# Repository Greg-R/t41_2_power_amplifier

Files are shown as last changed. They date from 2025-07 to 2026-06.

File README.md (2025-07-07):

# T41-2 Power Amplifier Version 1.7

This is the PCB for the Power Amplifier for the T41 "Software Defined Transceiver".
This PCB was designed using the open-source design tool Kicad 9.0.

The Power Amplifier is designed to driven by the T41-2 Low Power Amplifier, described here:

<https://github.com/Greg-R/t41_2_low_power_amplifier>

The Low Power Amplifier combined with the Power Amplifier are intended to replace the
original V11 Power Amplifier which uses IRF510 switching MOSFETs in the final amplifier
stage.  This new design will improve all aspects of power amplifier performance, 
including linearity, power, efficiency, and bandwidth.  An important difference is that
the amplifier operates from a 13.8 volt supply.  No "boost" module is required.

The schematic is here:

<https://github.com/Greg-R/t41_2_power_amplifier/blob/main/doc/t41_2_power_amplifier.pdf>

# Licensing

Please note the included license files.  The software license, GNU GENERAL PUBLIC LICENSE
Version 3, covers the design files.
The hardware license, CERN Open Hardware Licence Version 2 - Strongly Reciprocal, covers
the PCB and circuitry.

# Design Details

## Amplifier Design Notes 

The Power Amplifier is a conventional push-pull circuit using Mitsubishi RD16HHF1 devices.

The input network is an impedance matching transformer with a center-tapped secondary.
A resistive network is used for DC gate bias of the MOSFETS as well as for stability.
The two MOSFETs have independent bias adjustments due to the wide threshold voltage
variation of MOSFET devices.

A bifilar wound inductor provides DC bias to the MOSFET drains.

Each MOSFET has a transformer wound on a binocular core.  These are combined in parallel
on the output.  This results in a compact layout while preserving good bandwidth.

## DC Biasing and Thermal Protection Circuits 

A 10 volt regulator provides the bias voltage to the potentiometers which are used to set
the MOSFET quiescent bias currents.

There is also an optional "thermostat" device which shuts down the amplifier if the
temperature rises above a threshold set by a resistor value.  The thermostat is
positioned in close proximity to the output amplifier devices.  Experiments are
ongoing with this device to determine what temperature setting should be used.

Please note the electrolytic capacitors on the 13.8 volt supply net.  These are not
required in the case of a 13.8 volt supply voltage.  The 10uF ceramic capacitors, rated at
25 volts, are used in this case.  If it is desired to operate at a higher voltage, the
ceramics must be replaced with higher voltage electrolytics (not tested yet).

## Bill of Material

The Digikey BOM is here:

<https://www.digikey.com/en/mylists/list/1GX6JR00JS>

Four ferrite cores are required:

Quantity 2 BN-43-302 binocular cores.
Quantity 2 BN-43-202 binocular cores.

You will also need a small quantity of #24, #26, and #22 magnet wire.  I order this
on spools from Amazon:

<https://www.amazon.com/dp/B07DYF89T9?th=1>

I ordered the cores from:

<https://kitsandparts.com>

Also some hardware is required.  I used this outstanding heatsink:

<https://www.amazon.com/dp/B07TJY3GKP?th=1>

Some sort of stand-offs or spacers are required to hold the PCB above the heatsink.
These 5mm spacers are perfect:

<https://www.amazon.com/dp/B0CQ3TKVBD?th=1>

I use this type of caphead bolt to secure the PCB to the heatsink:

<https://www.amazon.com/dp/B0DYMYHHWH?th=1>

Two 3mm bolts and washers are required to bolt down the final amplifier devices.
A small amount of heatsink compound under the devices is recommended.

A 5 amp bladed style automotive fuse is required.

# Build Instructions

The Power Amplifier build is similar to the other boards in the T41-2 series,
with the exception being the ferrite cores which must be constructed with great
care.  I am going to create another document to cover the construction of the
three ferrite devices (T1, L2, T2 and T3).

The installation of the final amplifier devices Q1 and Q3 will be covered in
the same document as the ferrites.

The board has components on both sides.  I recommend using a hot plate for the
top side components.  Use a hot air gun for the bottom side components.

# Tune Up

## DC Bias Adjustment

There is an DC bias current adjustment for the two final amplifier MOSFETs.
The potentiometers are R17 and R11. 

It is important to set the potentiometers for minimal bias current before applying
power!!!  If the potentiometer is oriented as in the photograph (below) the 
potentiometer should be rotated counterclockwise until up against the stop.
Make sure both are set against the stop before proceeding with bias adjustment.

Since this is a Class-AB amplifier, the bias point should be set for optimal
linearity at the lowest current possible.

There is a trade-off here between linearity and efficiency.  The recommended
bias current was determined emperically.  However, if you want more efficiency,
and you are a CW operator only, decrease the bias current.  If you want even
more linearity for SSB operation, increase the bias current, with the 
trade-off being less amplifier efficiency.
 
The 13.8 volt current should be set for approximately 500 milliamperes per device
with no RF drive.  Slowly rotate one of the potentiometers clockwise until this current
is achieved.  The current may drift a few milliamperes as the devices warm up.
This is normal, and the exact bias current setting is not critical. Continue
with the second potentiometer until the total bias current is 1.0 amps. 

## Linearity Testing

The T41EEE firmware includes a "two-tone" test which can be used to evaluate the
linearity of a power amplifier.

# High Resolution Photos

The top side of the completed board:

<https://drive.google.com/file/d/1ic4hn-198JwR1nAGYp5Wp3Prv69H474b/view?usp=drive_link>

Side view of the completed module, showing the heatsink, TO-220 devices, and spacers:

<https://drive.google.com/file/d/1cEXMb9Utur-sG8AnGmGLAzppEAz-hgnM/view?usp=drive_link>

End view of the Power Amplifier, showing the spacers and heatsink:

<https://drive.google.com/file/d/1fRfvSwTNmH1s3oaT6EwBXt0dI4ggvO0P/view?usp=drive_link>

# Mounting the Power Amplifier to the T41 Radio

By drilling and tapping four holes in the extension of the heatsink, the Power
Amplifier module can be mounted to the back side of the radio. 

The FreeCad design file for a rear case panel is here:

<https://github.com/Greg-R/SDT_Case_KF5N/tree/main/case>

There are a lot of files in that folder.  The revised rear panel is:

Rear\_Full\_panel\_2025\_KF5N\_2.FCStd

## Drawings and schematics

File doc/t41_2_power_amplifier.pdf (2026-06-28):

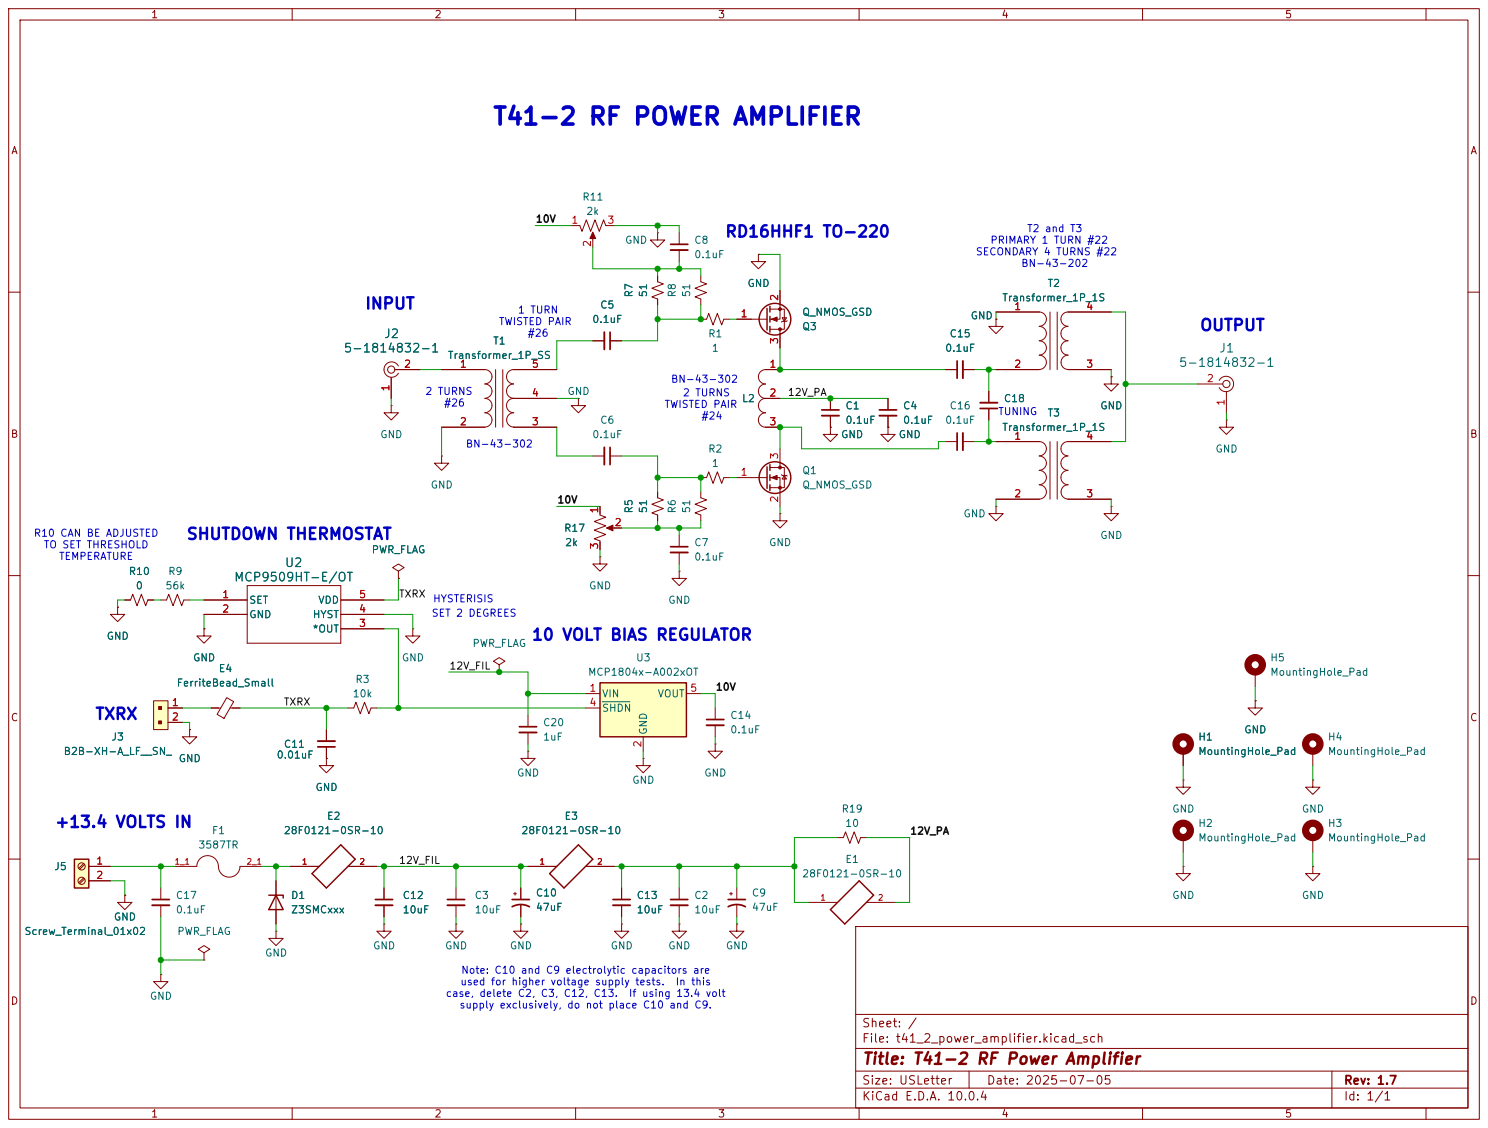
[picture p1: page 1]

SECONDARY 4 TURNS #22 BN-43-202 BN-43-302 T41-2 RF POWER AMPLIFIER

#24 Note: C10 and C9 electrolytic capacitors are used for higher voltage supply tests. In this case, delete C2, C3, C12, C13. If using 13.4 volt supply exclusively, do not place C10 and C9.

TUNING 10 VOLT BIAS REGULATOR

Sheet: /
File: t41_2_power_amplifier.kicad_sch
Title: T41-2 RF Power Amplifier

Size: USLetter | Rev: 1.7
KiCad E.D.A. 10.0.4 | Id: 1/1

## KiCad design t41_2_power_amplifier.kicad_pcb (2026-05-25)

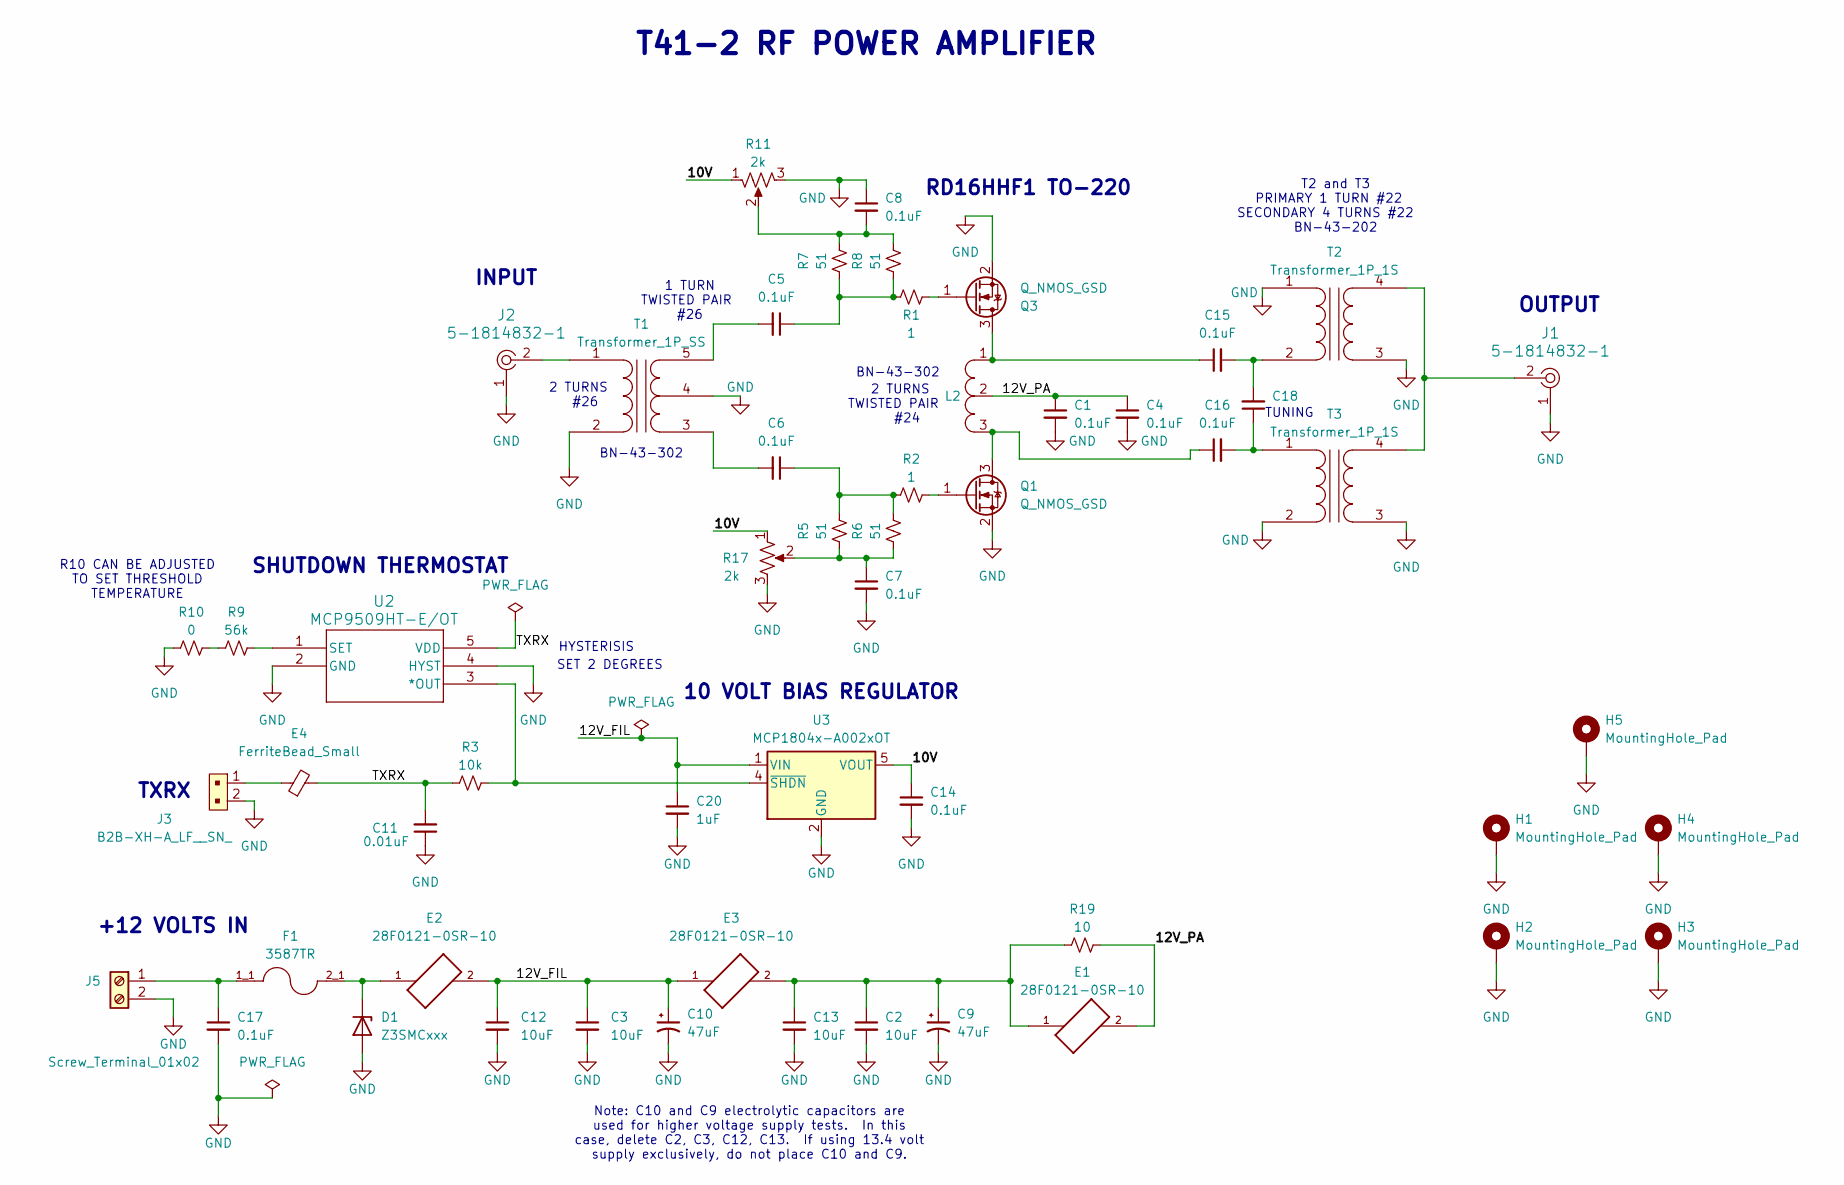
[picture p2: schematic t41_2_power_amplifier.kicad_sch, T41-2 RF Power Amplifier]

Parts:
C1, C4, C5, C6, C7, C8, C14, C15, C16, C17, C18: 0.1uF; C_1206_3216Metric
C2, C3, C12, C13: 10uF; C_1206_3216Metric
C9, C10: 47uF; CP_Elec_6.3x5.7
C11: 0.01uF; C_1206_3216Metric
C20: 1uF; C_1206_3216Metric
D1: Z3SMCxxx; D_SMC
E1, E2, E3: 28F0121-0SR-10; FB_28F0121-0SR-10; PARTREV J
E4: FerriteBead_Small; L_1206_3216Metric
F1: 3587TR; FUSE_3587TR; PARTREV D
H1, H2, H3, H4, H5: MountingHole_Pad; MountingHole_4.3mm_M4_DIN965_Pad
J1, J2: 5-1814832-1; RF_SMA_Vertical_5-1814832-1; MPN 5-1814832-1; Digi-Key_PN A97594-ND
J3: B2B-XH-A_LF__SN_; PinHeader_1x2_P2.5mm_Drill1.1mm; MPN B2B-XH-A(LF)(SN); Digi-Key_PN 455-2247-ND
J5: Screw_Terminal_01x02; TerminalBlock_Philmore_TB132_1x02_P5.00mm_Horizontal
L2: BN-43-202_VERTICAL
Q1, Q3: Q_NMOS_GSD; TO-220_RF_Flat_Through_Hole
R1, R2: 1; R_1206_3216Metric
R3: 10k; R_1206_3216Metric
R5, R6, R7, R8: 51; R_1206_3216Metric
R9: 56k; R_1206_3216Metric
R10: 0; R_1206_3216Metric
R11, R17: 2k; Potentiometer_Bourns_3296W_Vertical
R19: 10; R_1206_3216Metric
T1: Transformer_1P_SS; BN-43-302
T2, T3: Transformer_1P_1S; BN-43-202
U2: MCP9509HT-E/OT; SOT-23-5_MC_MCH
U3: MCP1804x-A002xOT; SOT-23-5

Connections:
/10V: C14.1, R11.1, R17.1, U3.5 (VOUT)
/12V_FIL: C3.1, C10.1, C12.1, C20.1, E2.2, E3.1, U3.1 (VIN)
/12V_PA: C1.1, C4.1, E1.2, L2.2, R19.2
/TXRX: C11.2, E4.2, R3.1, U2.5 (VDD)
GND: C1.2, C2.2, C3.2, C4.2, C7.2, C8.1, C9.2, C10.2, C11.1, C12.2, C13.2, C14.2, C17.2, C20.2, D1.2 (A), H1.1, H2.1, H3.1, H4.1, H5.1, J1.1, J2.1, J3.2, J5.2, Q1.2 (S), Q3.2 (S), R10.1, R11.3, R17.3, T1.2 (AB), T1.4 (SC), T2.1 (AA), T2.3 (SA), T3.2 (AB), T3.3 (SA), U2.2 (GND), U2.4 (HYST), U3.2 (GND)
unnamed: C5.1, R1.1, R7.1, R8.1
unnamed: C6.1, R2.1, R5.2, R6.2
unnamed: C7.1, R5.1, R6.1, R17.2
unnamed: C8.2, R7.2, R8.2, R11.2
unnamed: C2.1, C9.1, C13.1, E1.1, E3.2, R19.1
unnamed: D1.1 (K), E2.1, F1.2_1
unnamed: E4.1, J3.1
unnamed: C17.1, F1.1_1, J5.1
unnamed: C16.1, L2.3, Q1.3 (D)
unnamed: Q1.1 (G), R2.2
unnamed: C15.1, L2.1, Q3.3 (D)
unnamed: Q3.1 (G), R1.2
unnamed: R9.1, R10.2
unnamed: J2.2, T1.1 (AA)
unnamed: C6.2, T1.3 (SA)
unnamed: C5.2, T1.5 (SB)
unnamed: C15.2, C18.2, T2.2 (AB)
unnamed: J1.2, T2.4 (SB), T3.4 (SB)
unnamed: C16.2, C18.1, T3.1 (AA)
unnamed: R3.2, U2.3 (*OUT), U3.4 (~SHDN)
unnamed: R9.2, U2.1 (SET)

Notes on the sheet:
OUTPUT
BN-43-302
RD16HHF1 TO-220
SHUTDOWN THERMOSTAT
R10 CAN BE ADJUSTED TO SET THRESHOLD TEMPERATURE
Note: C10 and C9 electrolytic capacitors are used for higher voltage supply tests. In this case, delete C2, C3, C12, C13. If using 13.4 volt supply exclusively, do not place C10 and C9.
TUNING
2 TURNS #26
+12 VOLTS IN
1 TURN TWISTED PAIR #26
TXRX
T41-2 RF POWER AMPLIFIER
2 TURNS TWISTED PAIR #24
T2 and T3 PRIMARY 1 TURN #22 SECONDARY 4 TURNS #22 BN-43-202
INPUT
10 VOLT BIAS REGULATOR
HYSTERISIS
SET 2 DEGREES

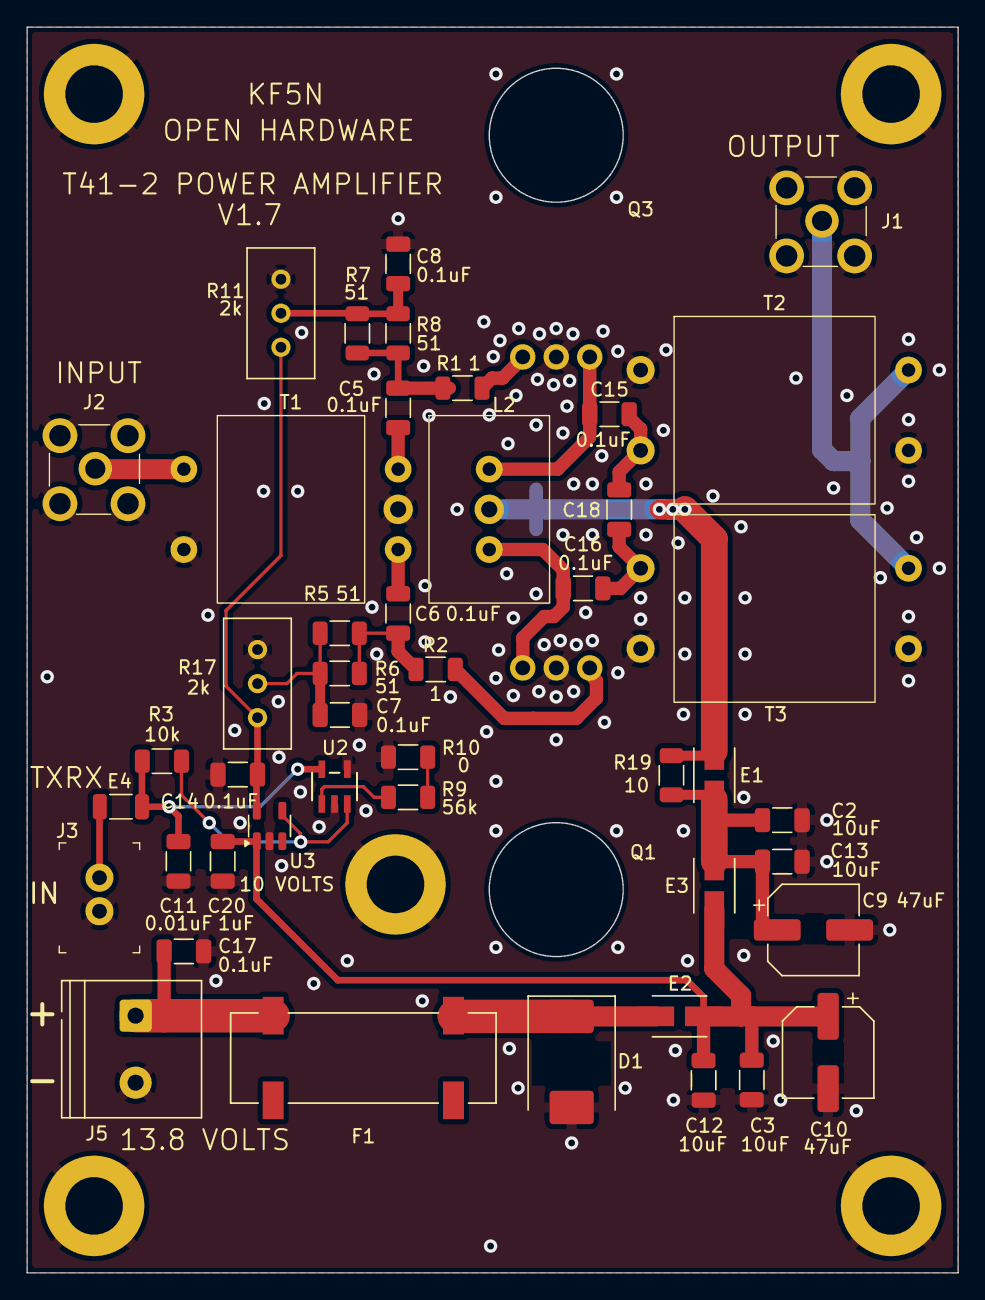
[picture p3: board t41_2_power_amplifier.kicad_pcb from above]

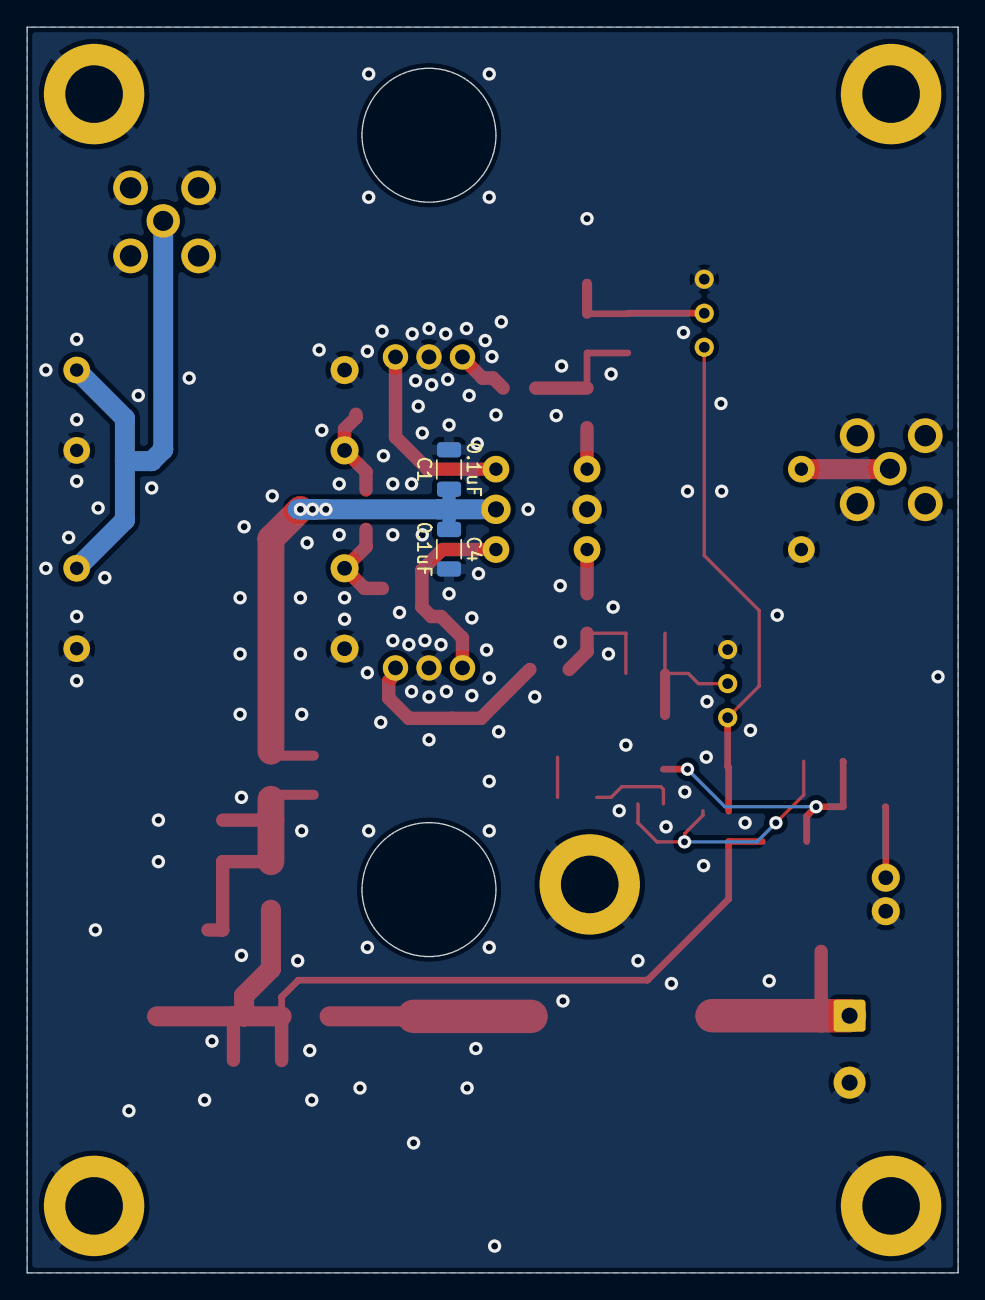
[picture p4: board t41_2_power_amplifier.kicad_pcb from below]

Board: 2 copper layers, 69.5 x 93.0 mm, 54 parts (2 on the bottom side), 26 nets.

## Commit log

2024-10-09 Initial commit.
    [t41_2_power_amplifier.kicad_pcb, t41_2_power_amplifier.kicad_sch]
2024-10-10 Schematic complete, started on layout.
    [t41_2_power_amplifier.kicad_pcb, t41_2_power_amplifier.kicad_sch]
2024-10-12 Branching to no-feedback experiment.
    [t41_2_power_amplifier-B_Cu.gbr, t41_2_power_amplifier-B_Mask.gbr, t41_2_power_amplifier-B_Silkscreen.gbr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]
2024-10-12 Finishing PCB placement. Stopping point.
    [t41_2_power_amplifier.kicad_pcb, t41_2_power_amplifier.kicad_sch]
2024-10-12 Routed. Needs cleanup.
    [t41_2_power_amplifier.kicad_pcb, t41_2_power_amplifier.kicad_sch]
2024-10-12 Almost ready for fab.
    [t41_2_power_amplifier.kicad_pcb]
2024-10-13 Beefed up main supply trace to final.
    [t41_2_power_amplifier.kicad_pcb]
2024-10-13 Added another stage to the input.
    [t41_2_power_amplifier.kicad_pcb, t41_2_power_amplifier.kicad_sch]
2024-10-14 Release V1.0.
    [t41_2_power_amplifier-B_Cu.gbr, t41_2_power_amplifier-B_Mask.gbr, t41_2_power_amplifier-B_Silkscreen.gbr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]
2024-10-24 Updated resistor values.
    [t41_2_power_amplifier.kicad_sch]
2024-12-01 Clean-up prior to branch.
    [t41_2_power_amplifier.kicad_sch]
2024-12-01 Power Amplifier module ready for fab.
    [t41_2_power_amplifier-B_Cu.gbr, t41_2_power_amplifier-B_Mask.gbr, t41_2_power_amplifier-B_Silkscreen.gbr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]
2024-12-22 Larger output balun design to fab.
    [t41_2_power_amplifier-B_Cu.gbr, t41_2_power_amplifier-B_Mask.gbr, t41_2_power_amplifier-B_Silkscreen.gbr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]
2024-12-22 T41-2 Power Amplifier S to fab.
    [t41_2_power_amplifier-B_Cu.gbr, t41_2_power_amplifier-B_Mask.gbr, t41_2_power_amplifier-B_Silkscreen.gbr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]
2024-12-23 Forgot to create zip of Gerbers.
2025-01-19 Power Amplifier to fab.
    [t41_2_power_amplifier-B_Cu.gbr, t41_2_power_amplifier-B_Mask.gbr, t41_2_power_amplifier-B_Silkscreen.gbr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]
2025-01-19 Forgot to add gerbers.
2025-04-19 Added zip files.
    [t41_2_power_amplifier.kicad_pcb, t41_2_power_amplifier.kicad_sch]
2025-04-23 Released to fab.
    [t41_2_power_amplifier-B_Cu.gbr, t41_2_power_amplifier-B_Mask.gbr, t41_2_power_amplifier-B_Silkscreen.gbr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]
2025-05-04 Updated PDF schematic.
2025-05-04 Nothing but Kicad update.
2025-05-04 Added through hole TO-220 footprint.
2025-05-05 Added notes to schematic.
    [t41_2_power_amplifier-B_Cu.gbr, t41_2_power_amplifier-B_Mask.gbr, t41_2_power_amplifier-B_Silkscreen.gbr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]
2025-05-21 Version 1.6 first commit.
    [t41_2_power_amplifier.kicad_pcb]
2025-05-31 Added new bypass capacitors. Added thermostat circuit.
    [t41_2_power_amplifier.kicad_pcb, t41_2_power_amplifier.kicad_sch]
2025-06-02 Version 1.6 to fab.
    [t41_2_power_amplifier-B_Cu.gbr, t41_2_power_amplifier-B_Mask.gbr, t41_2_power_amplifier-B_Silkscreen.gbr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]
2025-06-16 Work in progress.
    [t41_2_power_amplifier.kicad_sch]
2025-06-22 Version 1.7, release version to fab.
    [t41_2_power_amplifier-B_Cu.gbr, t41_2_power_amplifier-B_Mask.gbr, t41_2_power_amplifier-B_Silkscreen.gbr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]
2025-06-22 Added output tuning capacitor.
    [t41_2_power_amplifier-B_Cu.gbr, t41_2_power_amplifier-B_Mask.gbr, t41_2_power_amplifier-B_Silkscreen.gbr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]
2025-07-05 Initial commit to Github.
    [t41_2_power_amplifier-B_Cu.gbr, t41_2_power_amplifier-B_Mask.gbr, t41_2_power_amplifier-B_Silkscreen.gbr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]
2025-07-05 More clean up of initial push to Github.
    [t41_2_power_amplifier-B_Cu.gbr, t41_2_power_amplifier-B_Mask.gbr, t41_2_power_amplifier-B_Silkscreen.gbr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]
2025-07-05 Cleaning up initial push to Github.
    [t41_2_power_amplifier-B_Cu.gbr, t41_2_power_amplifier-B_Mask.gbr, t41_2_power_amplifier-B_Silkscreen.gbr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]
2025-07-07 Added README file.
    [t41_2_power_amplifier.kicad_sch]
2026-05-25 Added note about supply bypass capacitors.
    [t41_2_power_amplifier.kicad_pcb, t41_2_power_amplifier.kicad_sch]
2026-06-28 Changed supply voltage on schematic from 12 to 13.4 volts.
    [t41_2_power_amplifier.kicad_sch]
